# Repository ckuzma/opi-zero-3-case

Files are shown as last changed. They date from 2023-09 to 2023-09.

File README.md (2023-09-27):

# opi-zero-3-case
3D printable housing (of sorts) for the Orange Pi Zero 3.

## Description

This is a 3D-printable vented housing for the OrangePi Zero 3 single board computer that offers protection for the components and GPIO pins while still allowing for the use of heatsinks. In addition it features a built-in holder for the WiFi antenna.

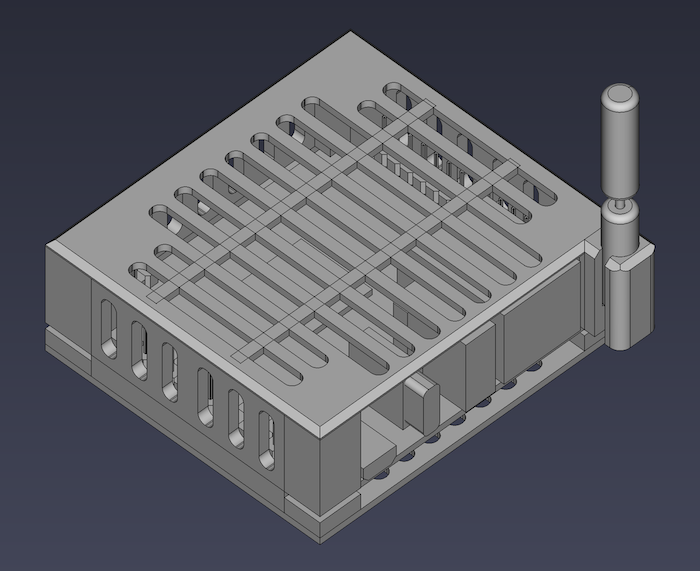
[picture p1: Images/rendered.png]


The two halves in ready-to-print STL format can be found here:

- [opi-zero-3-case/Printable_STLs/](./Printable_STLs/)

## Print Settings Used

- Monoprice PLA (Gray) 1.75mm Diameter
- 0.4mm Nozzle, 215˚C Hotend, 50˚C Glass Print Bed
- 0.2mm Resolution
- 100% Infill
- No Skirt, No Support Rafts

## Required to Complete

- 4 x M3*8 Machine Screws (aka 8mm M3 screws)

    > **A Note About Screw Threading...**
    > 
    > At least in my case, it turned out that a hole with a 1.45mm radius (2.9mm diameter) was optimal for the M3 screws' threads to engage with.  For the sections of the design that required a clean pass-through of the screws, a 1.9mm radius (3.8mm diameter) was used.  These values might need to be adjusted according due to printer, filament, and environmental influences.
    >
    > Why this is important: _my other projects utilized different values_.  It is my hope to one day figure out a more reliably consistent dimensions to use for threaded versus unthreaded sockets, but that's a project for another day.

## Images

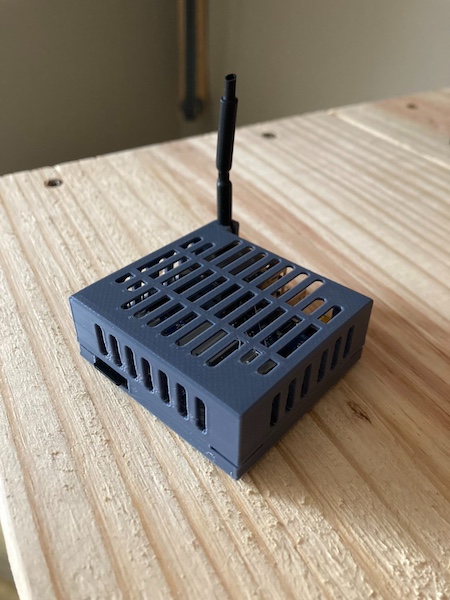
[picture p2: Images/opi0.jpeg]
finished1

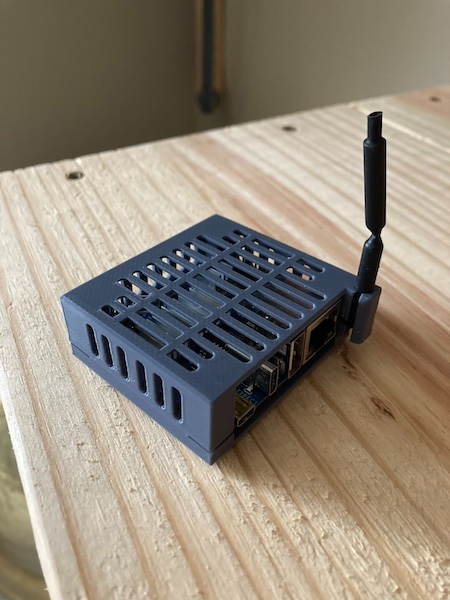
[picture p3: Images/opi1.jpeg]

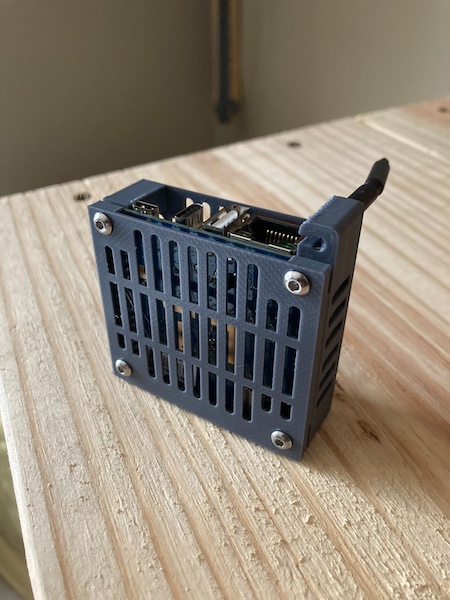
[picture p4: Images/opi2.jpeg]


## Special Thanks

This project was slow-going until I stumbled across [@MotorBottle](https://github.com/MotorBottle)'s [OrangePi-Zero3-CAD-3D-Model](https://github.com/MotorBottle/OrangePi-Zero3-CAD-3D-Model) project in which they provided a 3D model of the Orange Pi Zero 3.  Before then the only thing I had figured out was the exact spacing of the mounting holes on the board, but was having trouble with my standoff posts not fitting.  Once I stumbled across their model it was smooth sailing.

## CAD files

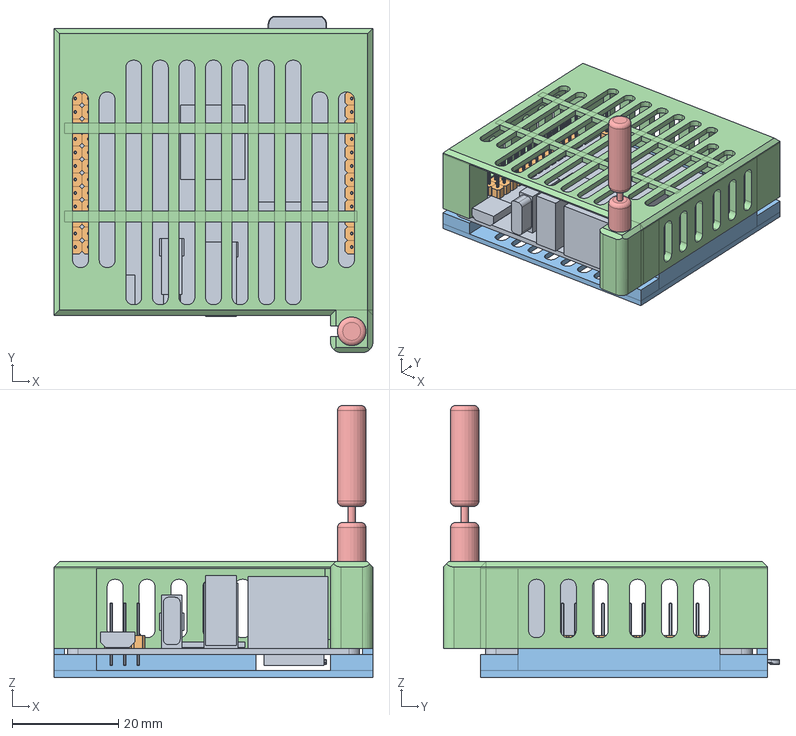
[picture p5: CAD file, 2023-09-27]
opi-zero-3-case.FCStd
60.0 x 63.2 x 51.2 mm
finished-bottom-plate-with-sides
finished-top-plate-wifi-fix
simulated-antenna

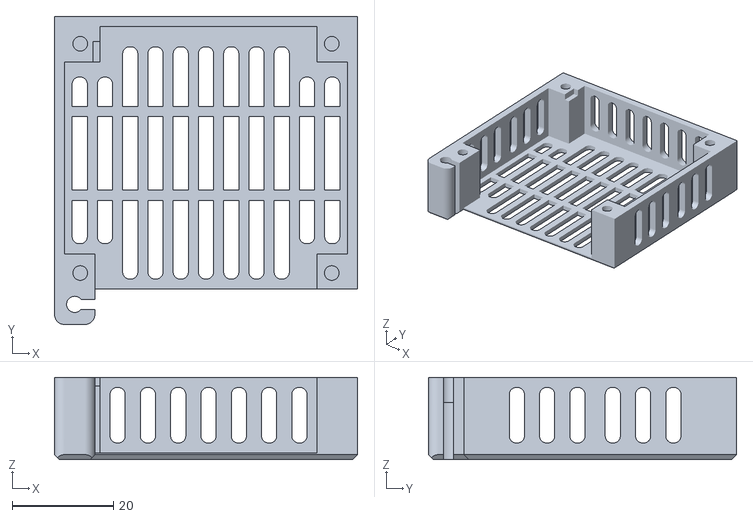
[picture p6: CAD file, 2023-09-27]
Printable_STLs/top-plate.stl
60.0 x 61.0 x 16.3

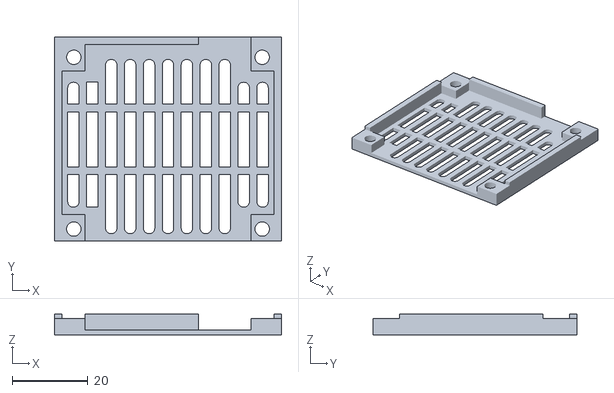
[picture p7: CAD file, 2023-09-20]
Printable_STLs/bottom-plate.stl
60.0 x 54.0 x 5.50

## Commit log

2023-08-01 Bottom plate should be functional
    [bottom-plate.FCStd, bottom-plate.stl]
2023-08-01 Tweaked model to attempt another fitment test, vented bottom plate
    [bottom-plate.FCStd, bottom-plate.stl]
2023-08-29 Updated design with enclosed walls and fixed thread pitch
    [bottom-plate.FCStd, bottom-plate.stl, opi-zero-3-case.FCStd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]
2023-09-20 Added antenna diameter test
    [antenna-test-antenna-test.stl, antenna-test.FCStd, opi-zero-3-case.FCStd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]
2023-09-20 Reduced diameter of threaded test, increased antenna diameter
    [antenna-test-antenna-test.stl, antenna-test.FCStd, threaded-screws-test.FCStd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]
2023-09-20 Figured out 1.45mm radius is best
    [threaded-screws-test.FCStd]
2023-09-20 2.7mm radius antenna cutout is the winner
    [antenna-test.FCStd]
2023-09-20 Added antenna to final design, fixed threaded screw radius
    [antenna-test.FCStd, bottom-plate.stl, opi-zero-3-case.FCStd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]
2023-09-25 Fixed (first try) the WiFi chip spacing that was needed
    [opi-zero-3-case.FCStd, top-plate.stl]
2023-09-27 Updated readme with new photos, added instructions and photos, published printable STLs
    [antenna-test-antenna-test.stl, antenna-test.FCStd, bottom-plate.stl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]
2023-09-27 Updated rendered image
    [opi-zero-3-case.FCStd]
2023-09-27 Updated print settings
